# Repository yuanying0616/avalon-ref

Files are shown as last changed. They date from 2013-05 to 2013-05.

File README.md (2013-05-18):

avalon-ref
==========

Avalon Reference Documentation, Bill of Materials, Chip Communication and etc.

==========

disclaimer:
==========
current version of FPGA bitstream contains licensed parts we can not open source at the moment,
a licensed free version is being worked on that will be released in the future.

TODO:
=========
translate and upload bill of materials.
clean up and upload chip communication protocol.

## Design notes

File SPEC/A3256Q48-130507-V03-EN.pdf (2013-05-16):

A3256Q48-130507-V03-EN

Copyright 2012-2013 Avalon Project | 2013-05-07 | Page 1 of 14

A3256-Q48

# SHA256 Processor

# Datasheet

Version 0.3

## May. 7

th
, 2013

Notes1: The information is subject to change without notice. Before using this document, please confirm that this is the latest version. Notes2: Not all products and/or types are available in every country. Please check with sales representative for availability and additional information.

A3256Q48-130507-V03-EN

Copyright 2012-2013 Avalon Project | 2013-05-07 | Page 2 of 14

## Table of Content

A3256Q48-130507-V03-EN

## 1. GENERAL DESCRIPTION

A3256Q48 is a high-quality SHA256 Processor, targeted for high speed SHA256 hash calculation. The major applications for this chip is provide a chip level solution for SH256 related work.

Key Feature

- 300M Hash Rate, overclocking available.
- power consumption lower than 2W
- support chain-mode, drastically reduced controller I/O port requirement
- configured hash unit speed

## 2. SYSTEM ARCHITECTURE

Figure 2-1 Chip Architecture

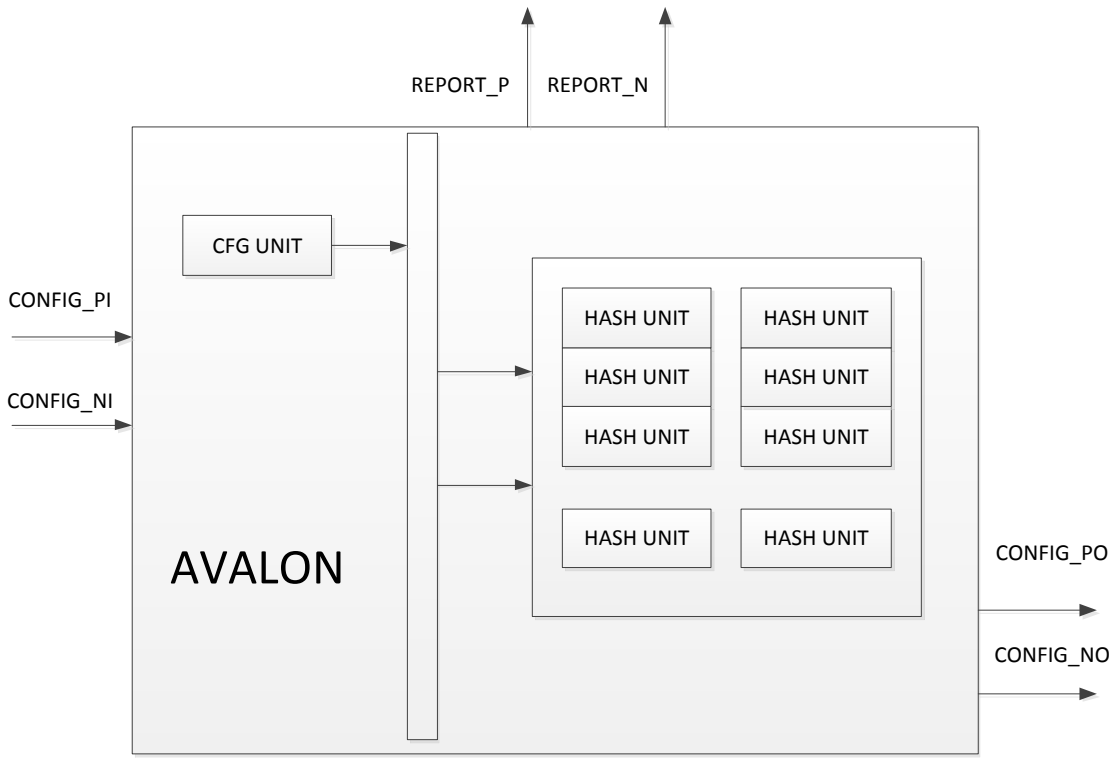
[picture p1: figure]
HASH UNIT HASH UNIT; HASH UNIT; CONFIG_PI; CONFIG_NI; CONFIG_PO; CONFIG_NO; REPORT_P; REPORT_N; AVALON

CFG UNIT | HASH UNIT HASH UNIT HASH UNIT | HASH UNIT

A3256Q48-130507-V03-EN

## 3. DATA INTERFACE

## 3.1 Communication Protocol

A3256Q48 uses a two-wire asynchronous serial communication protocol. Two wires, DATA_P and DATA_N carry information from transmitter to receiver. The two-wire bus has 3 states, IDLE, SEND0 and SEND1.Every transaction start with IDLE and when it finish, it should back to IDLE.

Figure 3-1 IDLE state

DATA_P

DATA_N

High

Low

High

Low

>125ns

>125ns Figure 3-1 shows bus IDLE state. When DATA_P=1 and DATA_N=1 last over 125ns, bus

enter into IDLE state, every transaction must start and end with IDLE state

Figure 3-2 SEND0 state

DATA_N

DATA_P

High

Low

High

Low

>125ns | >125ns

>250ns

Figure 3-2 shows bus SEND0 state. SEND0 could send one bit 0 to bus. SEND0 state starts with DATA_P=0 and DATA_N=0, after 125ns, DATA_P stays low and DATA_N transform from low to high and lasts over 125ns, then if no more bit to transfer DATA_P and DATA_N return to high, and bus is back to IDLE state.

A3256Q48-130507-V03-EN

Figure 3-3 SEND1 state

DATA_P

DATA_N

High

Low

High

Low

>125ns | >125ns

>250ns Figure 3-3 shows bus SEND1 state. SEND1 could send one bit 1 to bus. SEND1 state

starts with DATA_P=0 and DATA_N=0, after 125ns, DATA_N stays low and DATA_P transform from low to high and lasts over 125ns, then if no more bit to transfer DATA_P and DATA_N return to high, and bus is back to IDLE state.

Figure 3-4 Multi-bit transfer (0xCA)

DATA_N

DATA_P | High

Low

Low

High IDLE | SEND0 | SEND1 | SEND0 | SEND1 | SEND0 | SEND0 | SEND1 | SEND1 | IDLE Figure 3-4 shows bus state when sending 0xCA. Bus could transfer multi-bit without

IDLE state inside the transaction, multi-bit transaction start with IDLE state and then transfer data by SEND0 or SEND1. When the transaction finish, it should back to IDLE state.

## 3.2 Communication Port

A3256Q48 uses 6 communication ports to receive configurations, transmit the configurations to the chip at next stage and send out the calculation result, details are listed in Table 3.1

Table 3.1 A3256Q48 Communication Port
PIN NAME | PROTOCOL PORT | FUNCTION
CONFIG_PI | DATA_P | receive configurations from controller or another A3256Q48 chip
CONFIG_NI | DATA_N | receive configurations from controller or another A3256Q48 chip
CONFIG_PO | DATA_P | transmit the configurations to the chip at the next stage

A3256Q48-130507-V03-EN

CONFIG_NO | DATA_N | transmit the configurations to the chip at the next stage
REPORT_P | DATA_P | send out the golden nonce when A3256Q48 get the share
REPORT_N | DATA_N | send out the golden nonce when A3256Q48 get the share

## 4. DATA FORMAT

Three segments should be configured before A3256Q48 hash calculation by CONFIG_PI and CONFIG_NI. Clock configuration segment is for adjusting clock frequency, gating core clock or switching clock source. Hash data segment is the initial input data of SHA256 HASH. Hash work of chips in the same chain is split by the initial nonce segment. Configure data should send as the order shown in Figure 4-1

Figure 4-1 Configure Sequence

Initial Nonce | Hash Data | Clock Configuration
Last word | First word

When A3256Q48 get the nonce, it will return the nonce by REPORT_P and REPORT_N.

All input/output data is 32bit aligned, and send out in LSB(that means lowest bit send first).

## 4.1 Clock Configuration Segment

Clock configuration segment has two words (1word=32bit), detail information of each bit listed below.

bit[0]:Reserved, should be 1.
bit[1]:clock configuration effect bit, if this bit is 0, all clock configuration at current transaction is ineffective.
bit[2]:clock frequency effect bit, set to 1 if there are clock divider changes. bit[3]:clock gate, hash unit working clock will be gated it set to 1. bit[4]:clock will divided by 2 if set to 1
bit[5]:clock switch, hash unit working clock will switch to XCLKIN if set to 1. bit[17:6]:Reserved, should be 0x30000
bit[28:18]:clock main divider N
bit[34:29]:clock input divider R
hash unit working clock frequency = XCLKIN frequency * N/(2*R). N and R configuration should satisfy the following two conditions:
0.2MHz < XCLKIN/(2*R) < 6MHz | 500MHz < XCLKIN*N/R < 900MHz
bit[63:35]:Reserved，should be 0x2e.

A3256Q48-130507-V03-EN

## 4.2 HASH Data Segment

To reduce cost and get higher speed, A3256Q48 put some pre-calculation out of the chip. Controller need to do this calculation and send the result to A3256Q48. Part of code is list below in pseudo code:
void functionpre_calc
for(i=0;i<64;i++)
{
t1=h+E1(e)+CH(e,f,g)+K[i]+w[i]; t2=E0(a)+MAJ(a,b,c);
h=g;
g=f;
f=e;
e=d+t1;
d=c;
c=b;
b=a;
a=t1+t2;
if(i=0) a0 = a;
if(i=1) a1 = a;
if(i=2) a2 = a;
if(i=0) e0 = e;
if(i=1) e1 = e;
if(i=2) e2 = e;
}
a0, a1, a2, e0, e1, e2 is the pre-calculation result should send to A3256Q48 (for further information, please refer to http://en.wikipedia.org/wiki/SHA256). The complete sequence of Hash Data Segment is shown in Figure 4-2

Figure 4-2 Hash Data Segment Transfer Sequence

a2 | midstate | e0 | e1 | e2 | a0 | a1 | data
Last word | First word

All data is sent in LSB, means low bit, low byte and low word is sent first

## 4.3 Initial Nonce Segment

Since A3256Q48 could work in chain mode, and different chips in the same chain receive the same HASH data, so initial nonce value is the only different that could

A3256Q48-130507-V03-EN

split the work. The length of this segment is N word, N is the chain length. After initial nonce value configuration, all A3256Q48 chips get their own initial nonce, and then they could work at different range. For an example, if 10 chips are in the same chain, the nonce range segment should be 10 word long, and the whole 2^32 nonce should be split to 10 different areas, the configuration is shown in Figure 4-3.

Figure 4-3 Initial Nonce Configuration Example (10 chips)

0x00000000 | 0x19999999 | 0x33333332 | 0x4ccccccb | 0x66666664 | 0x7ffffffd | 0x99999996 | 0xb333332f | 0xccccccc8 | 0xe6666661

As shown in figure 4-3, the 10 chips start to do hash calculation with their configured initial nonce after configuration.

## 4.4 Receive Nonce

AVALON will send out the nonce value only when it get shares. The REAL golden nonce and the received nonce satisfy the following equals:
Golden nonce = Received nonce – 0xC0
Only 32 bit nonce will be sent out, so that controller should save the whole hash data and match the result to work received

## 5. PIN ASSIGNMENTS

Signal Type | Description
P | Power/Ground
I | Input
O | Output
PU | Internal pull-up resistor
PD | Internal pull-down resistor
/ | Multi-function separator

## 5.1 System Control

PIN NO. | PAD NAME | TYPE | FUNCTION
45 | RSTN | I,PD | Hardware Reset signal, low voltage active.
10 | CLKOUT | O | Crystal Clock output from chip

A3256Q48-130507-V03-EN

PIN NO. | PAD NAME | TYPE | FUNCTION
9 | XCLKIN | I | Crystal Clock input to chip
44 | CORE_CLKOUT | O | Debug Clock output from chip

## 5.2 Function

PIN NO. | PAD NAME | TYPE | FUNCTION
1 | CONFIG_PI | I | Config Data input to chip
2 | CONFIG_NI | I | Config Data input to chip
36 | CONFIG_PO | O | Config Data output from chip
35 | CONFIG_NO | O | Config Data output from chip
17 | REPORT_N | O,PU | Hash Data output from chip, need pull up on PCB
18 | REPORT_P | O,PU | Hash Data output from chip, need pull up on PCB
30 | DBG0 | O | Debug Data output from chip
29 | DBG1 | O | Debug Data output from chip

## 5.3 Power Supply

PIN NO. | PAD NAME | TYPE | FUNCTION
38 | OVSS0 | P | 3.3V IO0 Ground
37 | OVDD0 | P | 3.3V IO0 Power
23 | OVSS1 | P | 3.3V IO1 Ground
24 | OVDD1 | P | 3.3V IO1 Power
3 | DVDD26 | P | 1.2V Digital Power
4 | DVDD0 | P | 1.2V Digital Power
5 | DVSS0 | P | 1.2V Digital Ground
6 | DVDD5 | P | 1.2V Digital Power
11 | DVDD29 | P | 1.2V Digital Power
12 | DVDD8 | P | 1.2V Digital Power
13 | DVDD9 | P | 1.2V Digital Power
14 | DVDD30 | P | 1.2V Digital Power
15 | DVDD11 | P | 1.2V Digital Power
16 | DVDD12 | P | 1.2V Digital Power
19 | DVDD1 | P | 1.2V Digital Power
20 | DVSS1 | P | 1.2V Digital Ground
21 | DVDD14 | P | 1.2V Digital Power
22 | DVDD33 | P | 1.2V Digital Power
25 | DVDD15 | P | 1.2V Digital Power
26 | DVDD34 | P | 1.2V Digital Power
27 | DVDD17 | P | 1.2V Digital Power
28 | DVDD19 | P | 1.2V Digital Power
31 | DVDD2 | P | 1.2V Digital Power
32 | DVSS2 | P | 1.2V Digital Ground

A3256Q48-130507-V03-EN

PIN NO. | PAD NAME | TYPE | FUNCTION
33 | DVDD36 | P | 1.2V Digital Power
34 | DVDD37 | P | 1.2V Digital Power
39 | DVDD38 | P | 1.2V Digital Power
40 | DVDD20 | P | 1.2V Digital Power
41 | DVDD3 | P | 1.2V Digital Power
42 | DVSS3 | P | 1.2V Digital Ground
43 | DVDD23 | P | 1.2V Digital Power
46 | DVDD40 | P | 1.2V Digital Power
47 | DVDD41 | P | 1.2V Digital Power
48 | DVDD25 | P | 1.2V Digital Power
7 | VDDA_PLL | P | 1.2V PLL Power
8 | VSSA_PLL | P | PLL Ground

## 5.4 A3256Q48 Pin-Pad Map

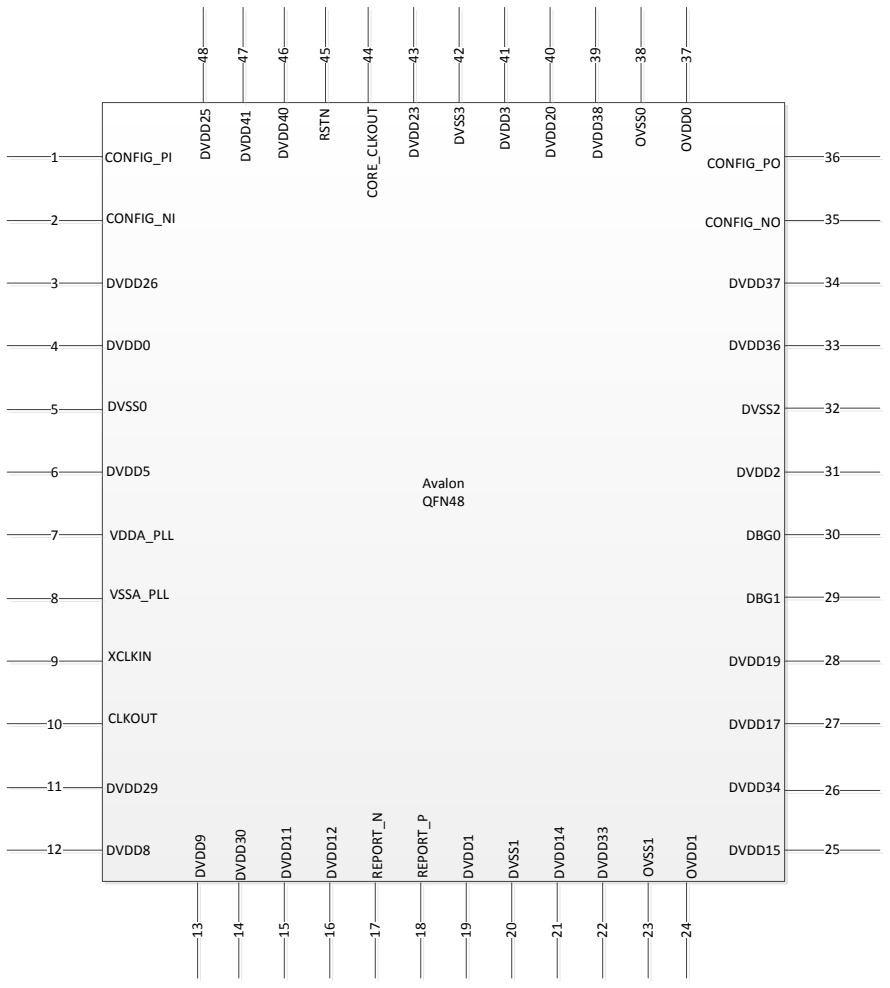
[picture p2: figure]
Avalon QFN48; VSSA_PLL; DVDD8; DVDD5; VDDA_PLL; 15 DVDD12 16 REPORT_N 17; 18 DVDD1 19 DVSS1 20 DVDD14 21; DVDD15; 27 DVDD34; 28 DVDD17; 29 DVDD19; 30 DBG1; 31 DBG0; 32 DVDD2; 33 DVSS2; 34 DVDD36; CLKOUT; 36 VDD²⁵; DVDD38; DVDD41; CONFIG_NO; CONFIG_PO ⁴⁴; DVDD20; DVDD3; DVSS3; 45 DVDD23; 46 RSTN CORE_CLKOUT; DVDD33; OVSS1; DVSS0; XCLKIN; CONFIG_PI CONFIG_NI DVDD26; DVDD0; DVDD11 DVDD30 DVDD9 13; 24 OVDD1; 47 DVDD40; OVSS0; 48 DVDD29; DVDD37; REPORT_P; OVDD0

A3256Q48-130507-V03-EN

## 6. ELECTRICAL CHARACTERISTICS

## 6.1 Recommended Operating Conditions

The recommended operating conditions are the recommended values to assure normal logic operation. As long as the device is used within the recommended operating conditions, the electrical characteristics (DC and AC characteristics) described below are assured.

PARAMETER. | SYMBOL | MIN | TYP | MAX | UNIT
Supply voltage Core | DVDD | 1.08 | 1.2 | 1.32 | V
Supply analog voltage 1.2V | VDDA_PLL | 1.08 | 1.2 | 1.32 | V
Supply voltage I/O | OVDD | 3.0 | 3.3 | 3.6 | V
Maximum input voltage | V i max | -- | -- | 3.6 | V
Operating Temperature | T OPR | -20 | -- | +85 | ℃
Storage Temperature | T STOR | -40 | -- | +150 | ℃
Operating Current | I OP | -- | -- | 2000 | mA
Static Current | I SUSP | -- | -- | 20 | mA

## 6.2 Oscillation

PARAMETER. | CONDI TIONS | SYMBOL | MIN | TYP | MAX | UNIT
Input clock frequency | -- | Fclixin | -- | 32 | -- | MHz
Input clock period | -- | Tclkxin | -- | 31.25 | -- | Ns
Clock duty cycle | -- | -- | 45 | 50 | 55 | %
Input pad capacitance | -- | -- | -- | 3.398 | -- | Pf
Jitter | -- | -- | -- | -- | 10 | Ps
Input HIGH leakage current | -- | -- | | -- | ±10 | uA
Input LOW leakage current | -- | -- | -- | -- | ±10 | uA

A3256Q48-130507-V03-EN

## 7. PACKAGE INFORMATION

## 7.1 Chip Marking Information

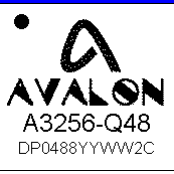
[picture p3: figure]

## 7.2 A3256Q48 Package Specifications

CHIP
MARING
INFORMATION

LEAD-FREE PACKAGE

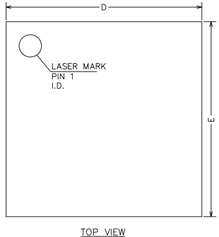
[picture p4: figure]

A3256Q48-130507-V03-EN

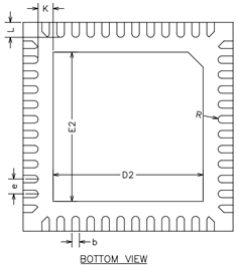
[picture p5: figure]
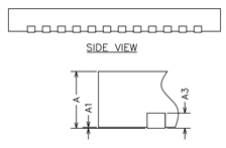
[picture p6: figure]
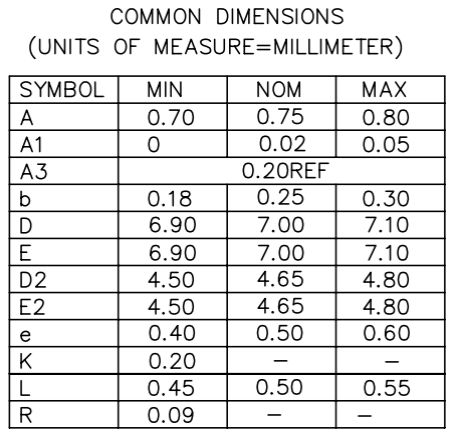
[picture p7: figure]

## 8. REVISION HISTORY

Version No. | Remarks | Release Date
0.1 | Initial version released for engineering review. | 2012-12-20
0.2 | New version for test | 2013-03-12
0.3 | Add protocol details | 2013-05-07

A3256Q48-130507-V03-EN

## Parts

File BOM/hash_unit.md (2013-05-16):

Comment|Description|Designator|Footprint|Quantity|Value|Remarks
--- | --- | --- | --- | --- | --- | --- 
680uF|SMD tantalum capacitors|C1, C13|D|2|680uF/2.5V|	
4.7uF|SMD ceramic capacitors|C2, C3|CAPC1608L|2|4.7uF/10V/X5R|	
10uF/16V|SMD ceramic capacitors|C4|CAPC3216L|1|10uF/16V/X7R|
270uF/16V|SMD solid state capacitors|C5|E12|1|270uF/16V|
22uF/16V|SMD ceramic capacitors|C6, C7|CAPC3225L|2|22uF/16V/X7R|
4.7uF/16V|SMD ceramic capacitors|C8, C17, C146|CAPC2012L|3|4.7uF/16V/X7R|	
6800pF|SMD ceramic capacitors|C9|CAPC1608L|1|6800pF/X7R|
1uF/20V|SMD ceramic capacitors|C10|CAPC1608L|1|1uF/20V/X7R|
1500uF/2.5V|SMD solid state capacitors|C11, C12|E12|2|1500uF/2.5V|	
47uF|SMD ceramic capacitors|C14|CAPC3225L|1|47uF/10V/X5R|	
10uF|SMD ceramic capacitors|C15, C18|CAPC2012L|2|10uF/10V/X5R|	
560pF|SMD ceramic capacitors|C16|CAPC1608L|1|560pF/NPO|
3900pF|SMD ceramic capacitors|C19|CAPC1608L|1|3900pF/NPO|	
22uF|SMD ceramic capacitors|C20, C21|CAPC3216L|2|22uF/10V/X5R|
0.47uF|SMD ceramic capacitors|C22, C23, C24, C25, C26, C27, C28, C29, C30, C31, C32, C33, C34, C35, C36, C37, C38, C39, C40, C41, C42, C43, C44, C45, C46, C47, C48, C49, C50, C51, C52, C53, C54, C55, C56, C57, C58, C59, C60, C61, C62, C63, C64, C65, C66, C67, C68, C69, C70, C71, C72, C73, C74, C75, C76, C77, C78, C79, C80, C81, C82, C83, C84, C85, C86, C87, C88, C89, C90, C91, C92, C93, C94, C95, C96, C97, C98, C99, C100, C101, C102, C103, C104, C105, C106, C107, C108, C109, C110, C111, C112, C113, C114, C115, C116, C117, C118, C119, C120, C121, C122, C123, C124, C125, C126, C127, C128, C129, C130, C131, C132, C133, C134, C135, C136, C137, C138, C139, C140, C141, C142, C143, C144, C145|CAPC1005L|124|0.47uF/6.3V/X5R|
MB|High current magnetic beads|FB1, FB2|INDC3216L|2|30 Ohm @100M|	
IHLP5050FDER|inductor|L1|IHLP5050|1|1R0|`OR` VISHAY IHLP5050FD `OR` Bourns SRP1270 `OR` Coilcraft XAL1010. R82~1R5, pads are common.
MB|magnetic beads|M1, M2, M3, M4, M5, M6, M7, M8, M9, M10, M11|RESC1005L|11|60 Ohm @100M|	
Header 10X2|10X2/2.54mm(female)|P1|20PINSMT|1|Pinhole facing outward
PSMN2R2-25YLC|MOS|Q1|LFPAK|1|		
NC|MOS|Q2|LFPAK|1||No soldering
CSD16403Q5A|MOS|Q3, Q4|LFPAK|2||		
0R|resistor|R1, R4|RESC1608L|2|0R|	
NC|resistor|R2, R25|RESC1005L|2|NC|No soldering
1K|resistor|R3|RESC1005L|1|1K|	
6.81K|resistor|R5|RESC1608L|1|6.81K/1%|	
10K|resistor|R6, R9|RESC1608L|2|10K/1%|	
3.9K|resistor|R7|RESC1608L|1|3.9K/1%|	
100K|resistor|R8, R12, R13, R14, R15, R16, R17, R18, R19, R20, R21|RESC1005L|11|100K|	
10.5K|resistor|R10|RESC1608L|1|10.5K/1%|	
909R|resistor|R11|RESC1608L|1|909R/1%|	
0R|resistor|R22, R26, R27|RESC1005L|3|0R|	
470R|resistor|R23, R24|RESC1005L|2|470R|	
TPS40193|DC-DC controller|U1|SON10|1||		
RT9166A_CXL|LDO|U2|SOT-89_M|1|1.2V|	
Avalon1|main control|U3, U4, U5, U6, U7, U8, U9, U10, U11, U12|QFN48NT7A|10||		
74LVC2G34|buffer|U13, U14, U15|SOT363_L|3||		
XTAL_32M|SMD active crystal oscillator|Y1|SMX2|1||32M

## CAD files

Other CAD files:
CAD/heat_sink/heatsink-a.dwg

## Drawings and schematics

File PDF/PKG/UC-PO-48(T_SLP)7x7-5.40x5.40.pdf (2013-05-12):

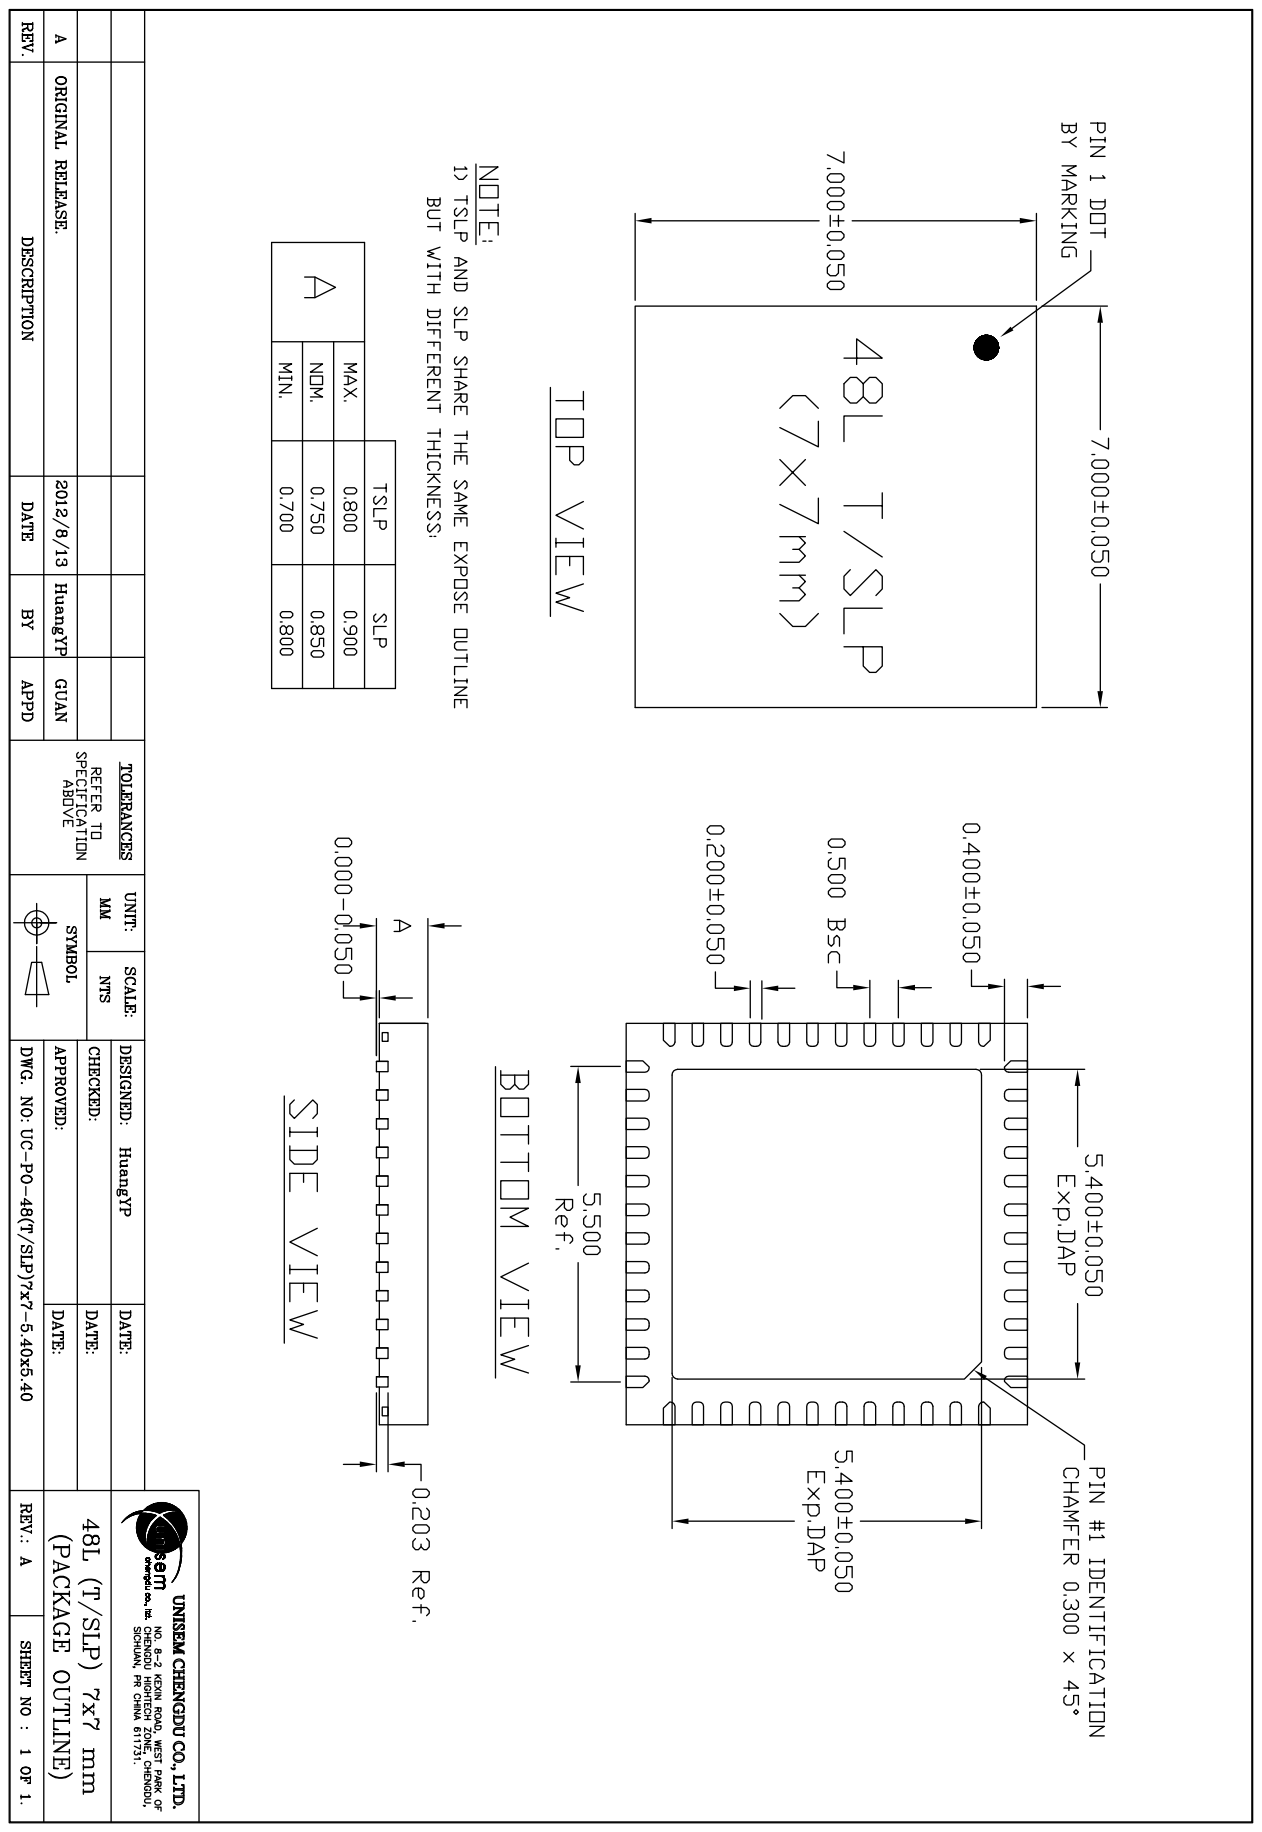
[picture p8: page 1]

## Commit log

2013-05-12 add heat_sink CAD
    [heatsink-a.dwg]
2013-05-16 incomplete bom for hash_unit / md table test
2013-05-16 finished hash_unit BOM
2013-10-05 upload 55nm chip data sheet
    low power mode: 0.8V 1Gh/s 1.5W
    typical: 0.9V 2.0W
    test: 1.4Gh/ at 1.15V
    more test required.
2013-10-19 A3255Q48: * Fix a wrong description of PLL power pin * Update package information
2013-11-21 Moved to http://downloads.canaan-creative.com/hardware/A3256/
    [AVALON_hashunit_chip.SchDoc, AVALON_hashunit_power.SchDoc, Avalon_BP.SchDoc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]
2013-11-23 Revert "Moved to http://downloads.canaan-creative.com/hardware/A3256/"
    This reverts commit 8b77fedb7b77544acc6ee86cd3fa62d735832fd7.
    [AVALON_hashunit_chip.SchDoc, AVALON_hashunit_power.SchDoc, Avalon_BP.SchDoc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]
